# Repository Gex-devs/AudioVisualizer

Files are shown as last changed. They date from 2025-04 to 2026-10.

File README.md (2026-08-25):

# STM32 Audio visualizer DOT MATRIX

Video

Audio Visualizer based on STM32 bluepill utilizing Fast FFT and hacky trick to make the Matrix LED working nicely together. 

## Compact Size

Made a Add-on type PCB that laches on the back of the LED matrix.

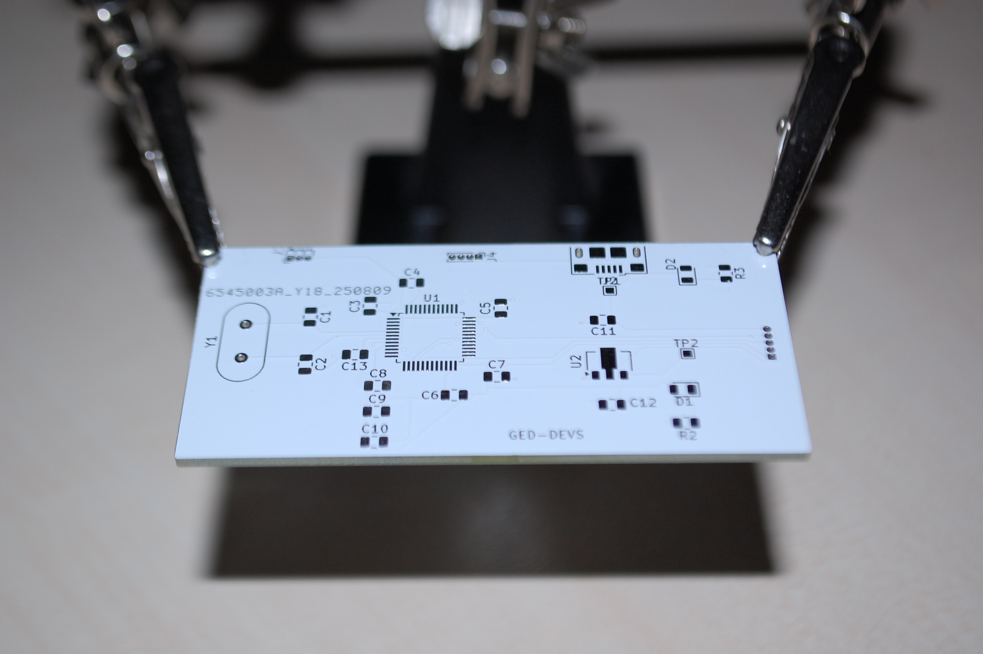
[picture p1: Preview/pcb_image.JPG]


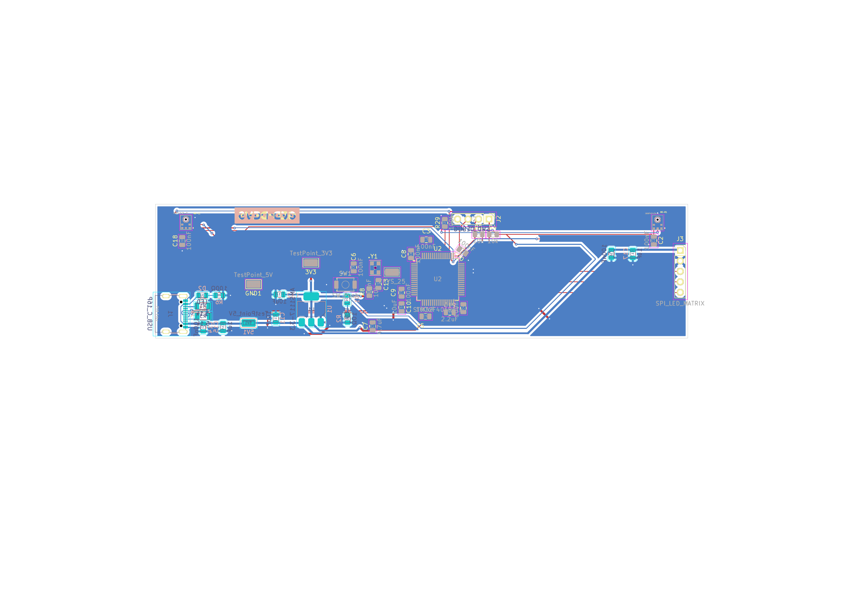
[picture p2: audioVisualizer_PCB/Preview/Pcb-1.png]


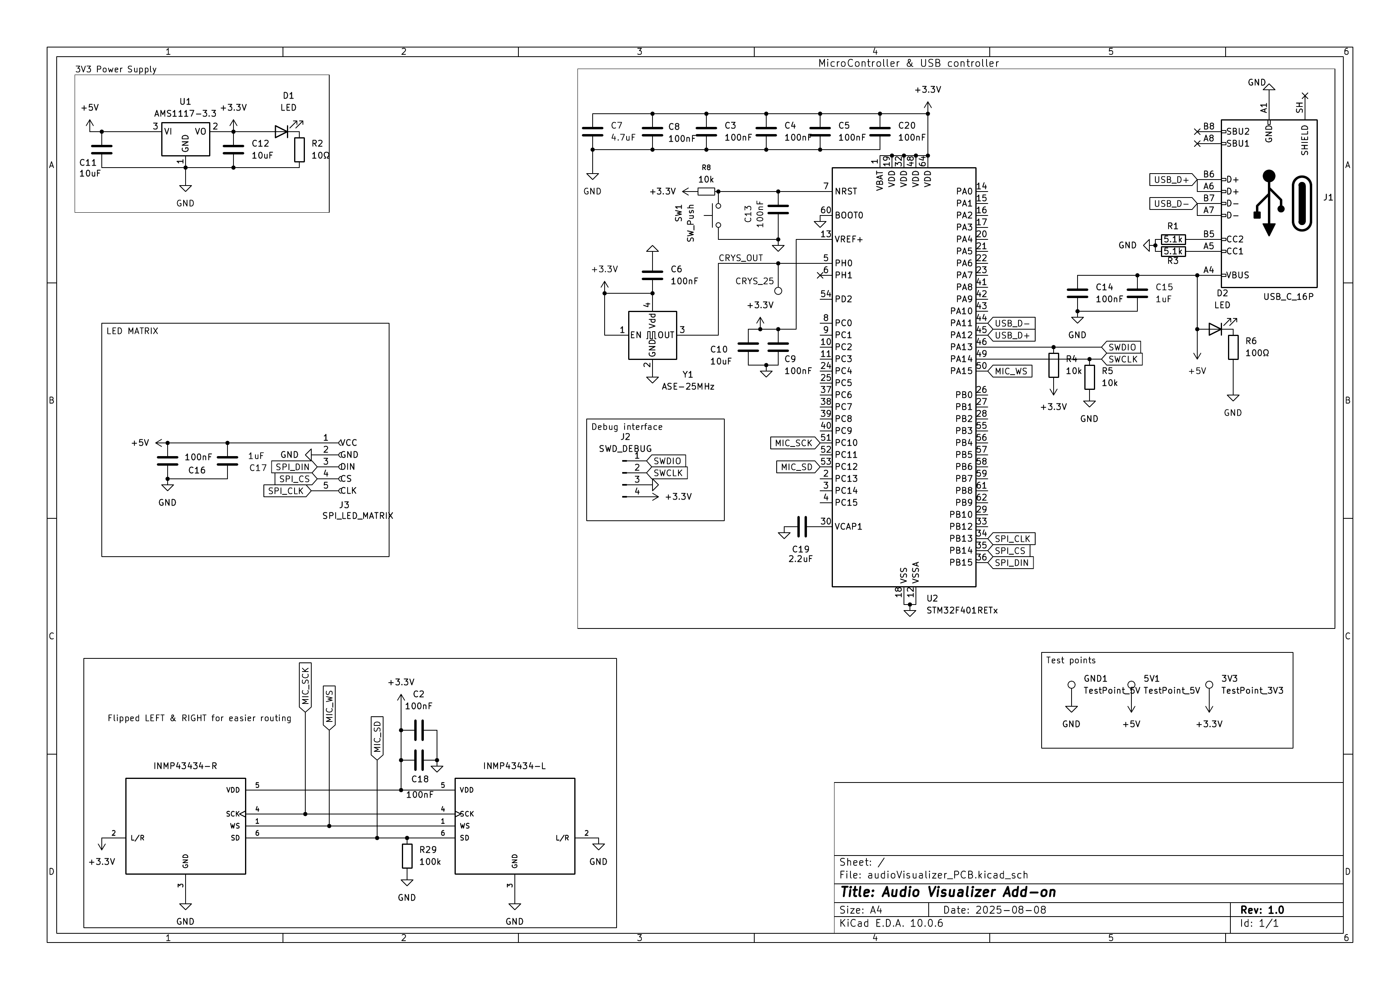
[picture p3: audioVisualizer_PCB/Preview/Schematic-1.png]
Document


## Components 
The Audio Visualizer features Real-time audio visualization with Fast Fourier Transform (FFT) to accurately visualize real audio frequencies rather than just detecting high or low noise levels.

* STM32 Bluepill
* MAX4466 Microphone Module
* 8x8 Matrix LED * 4

## Software Used

* [Kicad](https://www.kicad.org/) : PCB Design 
* [STM32MAX](https://www.st.com/en/development-tools/stm32cubemx.html) : Project Configurator 
* [T-filter](http://t-filter.engineerjs.com/) : Desgning Fir filter

## Tools Used

* Lab power supply
* Oscilloscope 
* ST-LINK/V2 debugger

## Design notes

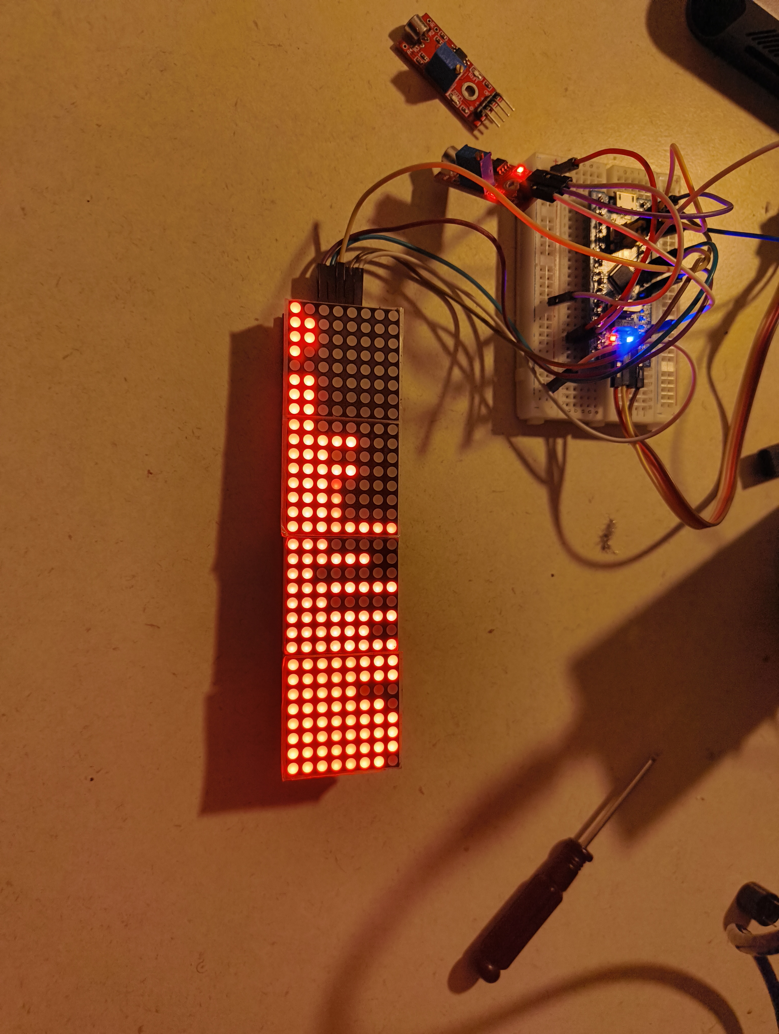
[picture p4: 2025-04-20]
Preview/Image.jpg

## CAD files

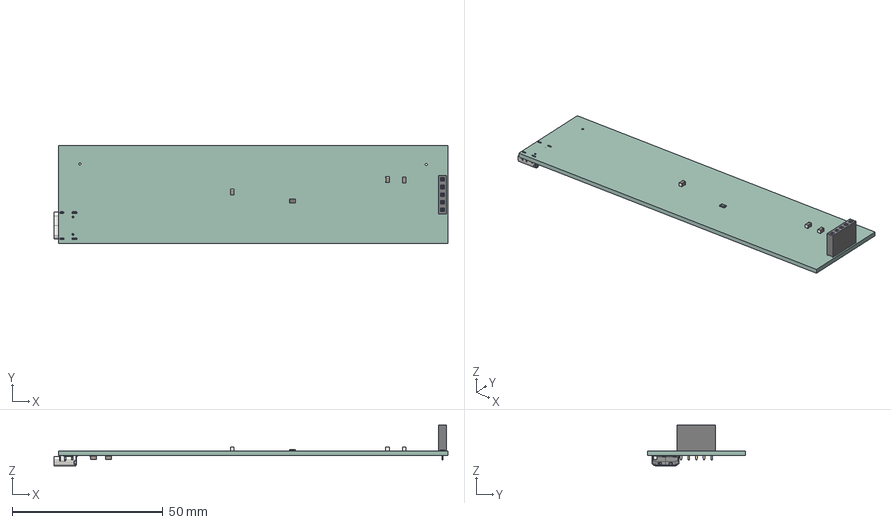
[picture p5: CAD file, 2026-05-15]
audioVisualizer_PCB/.step
130.6 x 32.5 x 13.5 mm
C_0805_2012Metric x 5
PinSocket_1x05_P2.54mm_Vertical
R_0805_2012Metric x 3
USB_C_Receptacle_GCT_USB4105-xx-A_16P_TopMnt_Horizontal
audioVisualizer_PCB_PCB

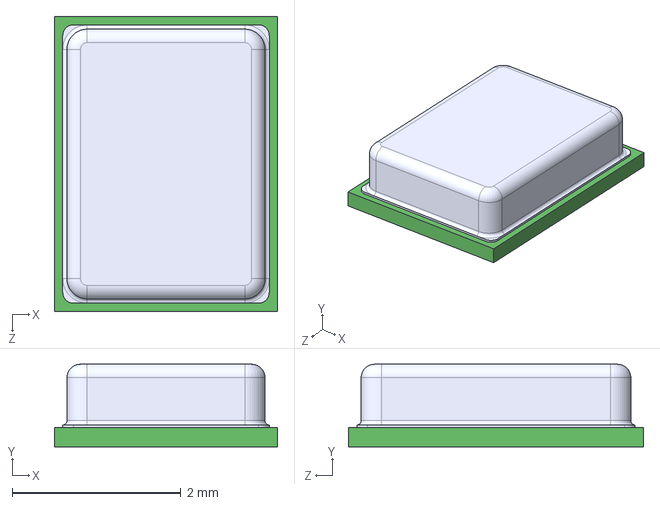
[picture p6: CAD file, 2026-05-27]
audioVisualizer_PCB/3dparts/ICS-43434.step
2.65 x 0.98 x 3.50 mm

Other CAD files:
audioVisualizer_PCB/Production/audioVisualizer_PCB-B_Paste.dxf

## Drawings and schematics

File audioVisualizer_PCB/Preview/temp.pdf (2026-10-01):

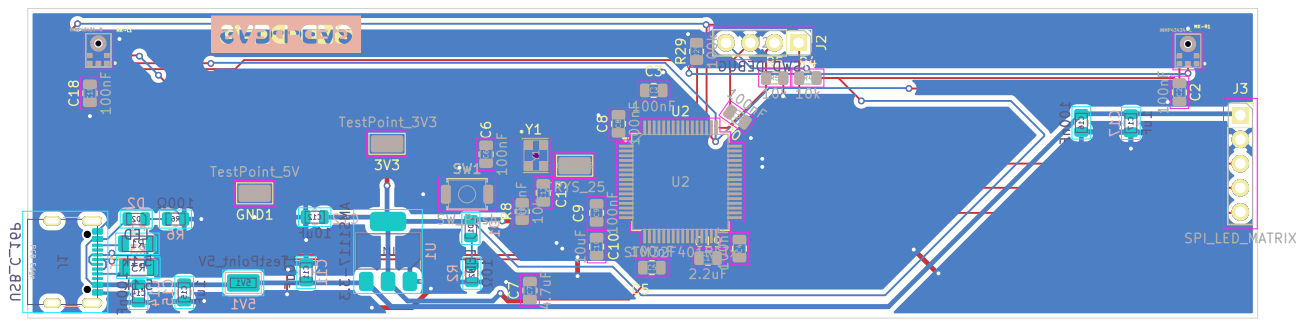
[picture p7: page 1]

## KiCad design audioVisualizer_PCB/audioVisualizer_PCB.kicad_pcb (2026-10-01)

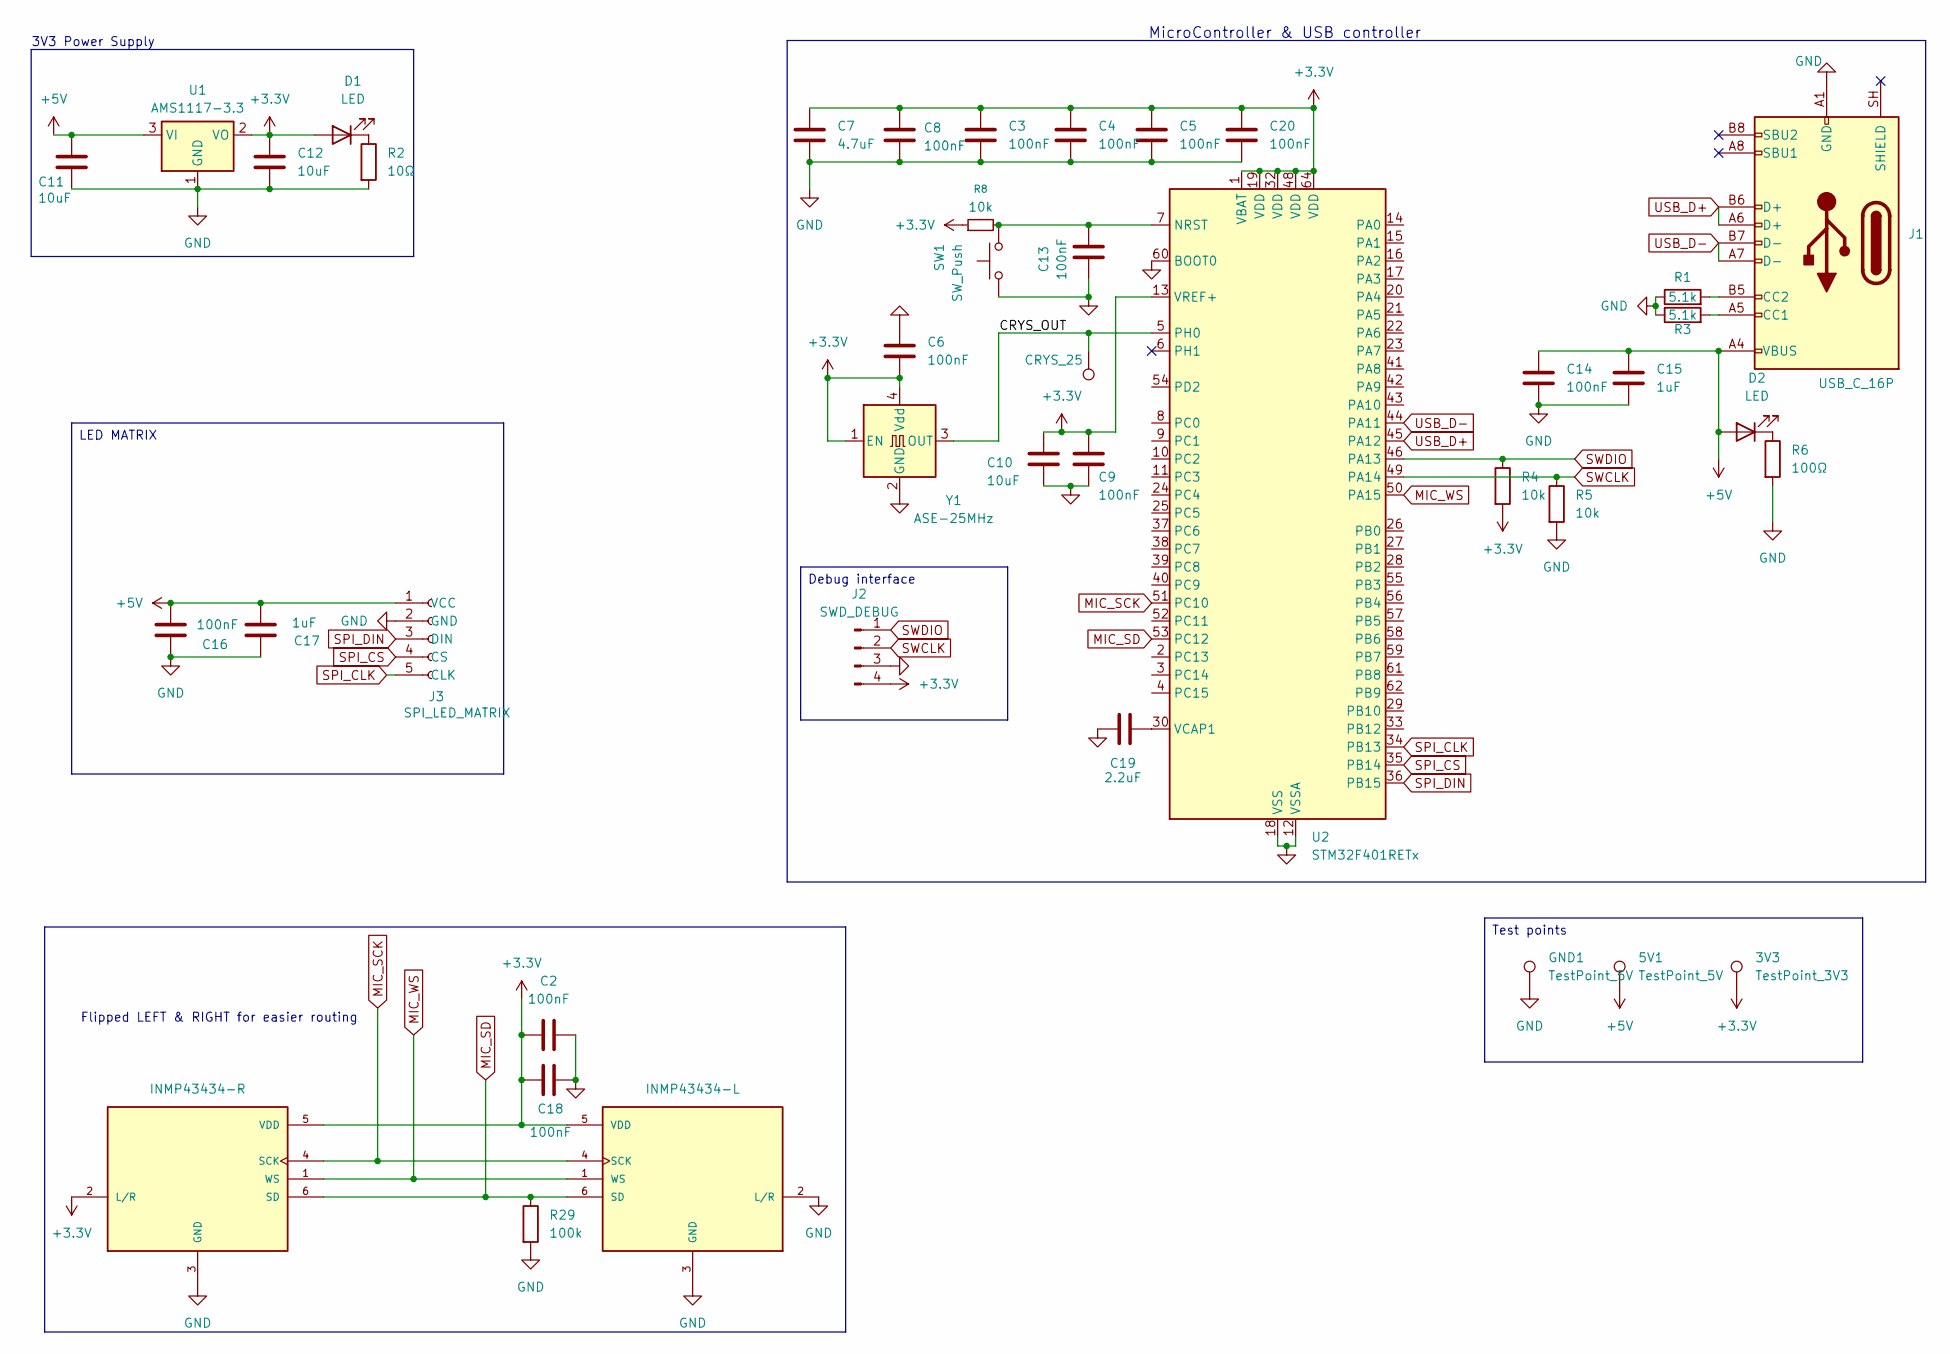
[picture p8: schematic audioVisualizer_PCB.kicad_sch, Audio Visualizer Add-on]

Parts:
3V3: TestPoint_3V3; TestPoint_Keystone_5015_Micro_Mini
5V1: TestPoint_5V; TestPoint_Keystone_5015_Micro_Mini
C2, C3, C4, C5, C6, C8, C9, C13, C14, C16, C18, C20: 100nF; C_0805_2012Metric
C7: 4.7uF; C_0805_2012Metric
C10, C11, C12: 10uF; C_0805_2012Metric
C15, C17: 1uF; C_0805_2012Metric
C19: 2.2uF; C_0805_2012Metric
CRYS_25: CRYS_25; TestPoint_Keystone_5015_Micro_Mini
D1, D2: LED; LED_0805_2012Metric
GND1: TestPoint_5V; TestPoint_Keystone_5015_Micro_Mini
J1: USB_C_16P; USB_C_Receptacle_GCT_USB4105-xx-A_16P_TopMnt_Horizontal
J2: SWD_DEBUG; PinHeader_1x04_P2.54mm_Vertical
J3: SPI_LED_MATRIX; PinSocket_1x05_P2.54mm_Vertical
MK-L1: INMP43434-R; MIC_ICS-43434; PARTREV 1.1
MK-R1: INMP43434-L; MIC_ICS-43434; PARTREV 1.1
R1, R3: 5.1k; R_1206_3216Metric
R2: 10Ω; R_0805_2012Metric
R4, R5, R8: 10k; R_0805_2012Metric
R6: 100Ω; R_0805_2012Metric
R29: 100k; R_0805_2012Metric
SW1: SW_Push; SW_SPST_TS-1088-xR020
U1: AMS1117-3.3; SOT-223-3_TabPin2
U2: STM32F401RETx; LQFP-64_10x10mm_P0.5mm
Y1: ASE-25MHz; Oscillator_SMD_EuroQuartz_XO32-4Pin_3.2x2.5mm

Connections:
+3.3V: 3V3.1 (1_1), C2.1, C3.1, C4.1, C5.1, C6.2, C7.1, C8.1, C9.1, C10.1, C12.1, C18.2, C20.1, D1.2 (A), J2.4, MK-L1.2 (L/R), MK-L1.5 (VDD), MK-R1.5 (VDD), R4.2, R8.1, U1.2 (VO), U2.1 (VBAT), U2.13 (VREF+), U2.19 (VDD), U2.32 (VDD), U2.48 (VDD), U2.64 (VDD), Y1.1 (EN), Y1.4 (Vdd)
+5V: 5V1.1 (1_1), C11.1, C14.2, C15.1, C16.2, C17.1, D2.2 (A), J1.A4 (VBUS), J1.A9 (VBUS), J1.B4 (VBUS), J1.B9 (VBUS), J3.1 (VCC), U1.3 (VI)
/CRYS_OUT: CRYS_25.1 (1_1), U2.5 (PH0), Y1.3 (OUT)
GND: C2.2, C3.2, C4.2, C5.2, C6.1, C7.2, C8.2, C9.2, C10.2, C11.2, C12.2, C13.2, C14.1, C15.2, C16.1, C17.2, C18.1, C19.2, C20.2, GND1.1 (1_1), J1.A1 (GND), J1.A12 (GND), J1.B1 (GND), J1.B12 (GND), J2.3, J3.2 (GND), MK-L1.3 (GND), MK-R1.2 (L/R), MK-R1.3 (GND), R1.1, R2.2, R3.1, R5.2, R6.2, R29.2, SW1.1, U1.1 (GND), U2.12 (VSSA), U2.18 (VSS), U2.31 (VSS), U2.47 (VSS), U2.60 (BOOT0), U2.63 (VSS), Y1.2 (GND)
MIC_SCK: MK-L1.4 (SCK), MK-R1.4 (SCK), U2.51 (PC10)
MIC_SD: MK-L1.6 (SD), MK-R1.6 (SD), R29.1, U2.53 (PC12)
MIC_WS: MK-L1.1 (WS), MK-R1.1 (WS), U2.50 (PA15)
unnamed: D1.1 (K), R2.1
unnamed: D2.1 (K), R6.1
unnamed: J1.A5 (CC1), R3.2
unnamed: J1.B5 (CC2), R1.2
unnamed: C13.1, R8.2, SW1.2, U2.7 (NRST)
unnamed: C19.1, U2.30 (VCAP1)
SPI_CLK: J3.5 (CLK), U2.34 (PB13)
SPI_CS: J3.4 (CS), U2.35 (PB14)
SPI_DIN: J3.3 (DIN), U2.36 (PB15)
SWCLK: J2.2, R5.1, U2.49 (PA14)
SWDIO: J2.1, R4.1, U2.46 (PA13)
USB_D+: J1.A6 (D+), J1.B6 (D+), U2.45 (PA12)
USB_D-: J1.A7 (D-), J1.B7 (D-), U2.44 (PA11)

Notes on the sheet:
MicroController & USB controller
3V3 Power Supply
Flipped LEFT & RIGHT for easier routing
Test points
Debug interface
LED MATRIX

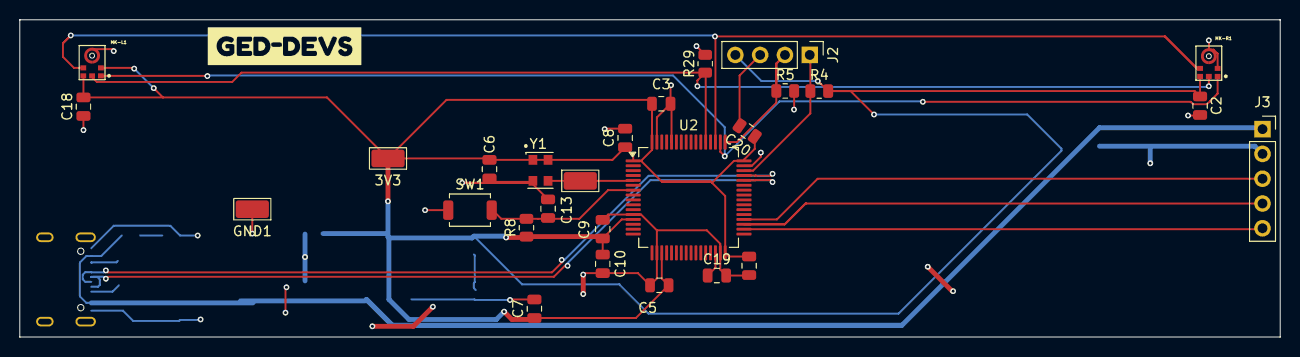
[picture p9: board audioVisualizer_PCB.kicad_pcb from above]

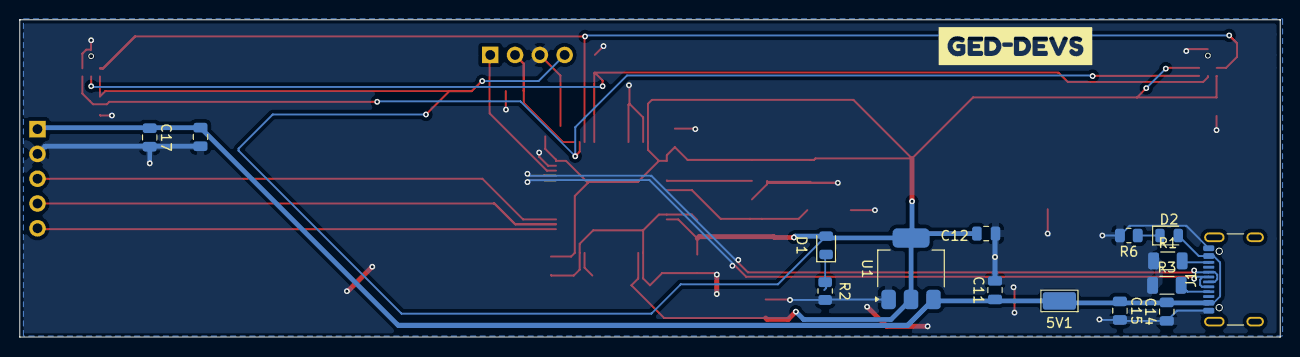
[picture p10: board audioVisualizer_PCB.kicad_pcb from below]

Board: 2 copper layers, 129.1 x 32.5 mm, 44 parts (16 on the bottom side), 20 nets.

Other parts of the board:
kibuzzard-69F6314F, kibuzzard-69F6314F#2: G***; kibuzzard-69F6314F

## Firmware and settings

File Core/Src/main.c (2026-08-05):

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
/* Includes ------------------------------------------------------------------*/
#include "main.h"

/* USER CODE BEGIN Includes */
#include <stdbool.h>
#include <stdlib.h>
#include <string.h>
#include <arm_math.h>
#include <arduino_utils.h>
/* USER CODE END Includes */

/* USER CODE BEGIN PTD */
typedef struct
{
  int bin_low;
  int bin_high;
} LogBinMap;
/* USER CODE END PTD */

/* USER CODE BEGIN PM */
#define MATRIX_DISPLAY_UNIT1 0
#define FFT_LENGTH 64
#define BUFFER_SIZE (FFT_LENGTH) // 24bits 32 data frame
#define MATRIX_X 32
#define MATRIX_Y 8

#define SAMPLE_RATE 16000.0f
#define MIN_FREQ 2000.0f
#define MAX_FREQ 7000.0f
/* USER CODE END PM */

I2S_HandleTypeDef hi2s3;

SPI_HandleTypeDef hspi2;

TIM_HandleTypeDef htim2;

UART_HandleTypeDef huart6;

HCD_HandleTypeDef hhcd_USB_OTG_FS;

/* USER CODE BEGIN PV */
bool i2s_dma_full_flag = false;
bool i2s_dma_half_flag = false;

arm_status status_fft;
arm_fir_instance_f32 fir;
arm_rfft_fast_instance_f32 fft_instance;

float32_t input_fft[FFT_LENGTH];
float32_t output_fft[FFT_LENGTH];
float32_t output_fft_mag[FFT_LENGTH / 2];
float32_t output_bins[MATRIX_X];
uint32_t i2s_buffer[BUFFER_SIZE];

LogBinMap lut[MATRIX_X];

float32_t window_coff[FFT_LENGTH];

float32_t data_avgs[MATRIX_X];

int yvalue;
int peaks[MATRIX_X] = {0};
int displaycolumn, displayvalue;

int MY_ARRAY[] = {0, 128, 192, 224, 240, 248, 252, 254, 255};

void build_log_bin_lut(LogBinMap *lut, int NUM_BINS)
{
  int fft_bins = FFT_LENGTH / 2;
  float32_t freq_resolution = SAMPLE_RATE / (float32_t)FFT_LENGTH;

  float32_t log_min = log2f(MIN_FREQ);
  float32_t log_max = log2f(MAX_FREQ);
  float32_t log_range = log_max - log_min;

  for (int i = 0; i < NUM_BINS; i++)
  {
    float32_t freq_low = powf(2.0f, log_min + (float32_t)i / NUM_BINS * log_range);
    float32_t freq_high = powf(2.0f, log_min + (float32_t)(i + 1) / NUM_BINS * log_range);

    int bin_low = (int)floorf(freq_low / freq_resolution);
    int bin_high = (int)ceilf(freq_high / freq_resolution);

    bin_low = bin_low < 0 ? 0 : bin_low;
    bin_high = bin_high >= fft_bins ? fft_bins - 1 : bin_high;

    if (bin_low > bin_high)
      bin_high = bin_low;

    lut[i].bin_low = bin_low;
    lut[i].bin_high = bin_high;
  }
}

void rebin_log_audio(float *fft_mag, float *rebin, const LogBinMap *lut, int NUM_BINS)
{
  for (int i = 0; i < NUM_BINS; i++)
  {
    int bin_low = lut[i].bin_low;
    int bin_high = lut[i].bin_high;

    float32_t sum = 0.0f;
    int count = bin_high - bin_low + 1;

    for (int j = bin_low; j <= bin_high; j++)
      sum += fft_mag[j];

    rebin[i] = sum / (float32_t)count;
  }
}
/*

FIR filter designed with
http://t-filter.appspot.com

sampling frequency: 16000 Hz

* 0 Hz - 3000 Hz
  gain = 0
  desired attenuation = -40 dB
  actual attenuation = -41.44566068037808 dB

* 4000 Hz - 8000 Hz
  gain = 1
  desired ripple = 5 dB
  actual ripple = 3.5163656958569183 dB

*/

#define FILTER_TAP_NUM 19

static float32_t filter_taps[FILTER_TAP_NUM] = {
    -0.01286737409931033,
    -0.011582917042481518,
    0.0709435597229363,
    -0.05850997474212666,
    -0.040910558942368495,
    0.03894710089289564,
    0.0947634922313574,
    -0.04258608472470373,
    -0.31412123784627477,
    0.543381234624982,
    -0.31412123784627477,
    -0.04258608472470373,
    0.0947634922313574,
    0.03894710089289564,
    -0.040910558942368495,
    -0.05850997474212666,
    0.0709435597229363,
    -0.011582917042481518,
    -0.01286737409931033};

float32_t firState[FILTER_TAP_NUM + FFT_LENGTH - 1];

/* USER CODE END PV */

void SystemClock_Config(void);
static void MX_GPIO_Init(void);
static void MX_I2S3_Init(void);
static void MX_SPI2_Init(void);
static void MX_USB_OTG_FS_HCD_Init(void);
static void MX_TIM2_Init(void);
static void MX_USART6_UART_Init(void);
/* USER CODE BEGIN PFP */
void audio_visualizer_update(float32_t *fft_magnitudes);
void process_audio_data(float32_t *output_fft_mag);
void test_visualizer_sine(void);
/* USER CODE END PFP */

/* USER CODE BEGIN 0 */
void test_visualizer_sine(void)
{
  static float32_t sweep_freq = 200.0f;
  static float32_t sweep_dir = 1.0f;

  float32_t phase_inc = 2.0f * M_PI * sweep_freq / 16000.0f; // 16kHz here
  float32_t ph = 0.0f;

  for (int i = 0; i < FFT_LENGTH; i++)
  {
    input_fft[i] = 500000.0f * sinf(ph);
    ph += phase_inc;
    if (ph >= 2.0f * M_PI)
      ph -= 2.0f * M_PI;
  }

  float32_t mean = 0.0f;
  for (int i = 0; i < FFT_LENGTH; i++)
    mean += input_fft[i];
  mean /= FFT_LENGTH;
  for (int i = 0; i < FFT_LENGTH; i++)
    input_fft[i] -= mean;
  for (int i = 0; i < FFT_LENGTH; i++)
    input_fft[i] *= window_coff[i];

  arm_rfft_fast_f32(&fft_instance, input_fft, output_fft, 0);
  arm_cmplx_mag_f32(output_fft, output_fft_mag, FFT_LENGTH / 2);
  audio_visualizer_update(output_fft_mag);

  // Sweep 200Hz → 7500Hz (stay safely below 8000Hz Nyquist limit)
  sweep_freq += sweep_dir * 200.0f;
  if (sweep_freq >= 7500.0f)
    sweep_dir = -1.0f;
  if (sweep_freq <= 200.0f)
    sweep_dir = 1.0f;

  HAL_Delay(80);
}

/**
 * @brief input i2s buffer, reconstuct and return magnitude, implemented for inmp411
 * @return float32_t
 */
void process_audio_data(float32_t *output_fft_mag)
{
  for (int i = 0; i < FFT_LENGTH - 1; i++)
  {
    int32_t left = i2s_buffer[i];
    int32_t right = i2s_buffer[i + 1];

    // squre the audio channels
    right = right * right; // R^2
    left = left * left;    // L^2

    // root mean square https://en.wikipedia.org/wiki/Root_mean_square
    double sample = sqrt((left + right) / 2);
    // int32_t sample = (left + right) / 2; // average

    input_fft[i] = (float32_t)sample; // Store in FFT input buffer as float
  }

  // Applying High-pass filter
  // arm_fir_f32(&fir, input_fft, input_fft, FFT_LENGTH);

  float mean = 0;
  for (int i = 0; i < FFT_LENGTH; i++)
  {
    mean += input_fft[i]; // Calculate mean for DC offset removal
  }
  mean /= FFT_LENGTH;

  for (int i = 0; i < FFT_LENGTH; i++)
  {
    input_fft[i] -= mean; // DC offset removal
  }

  for (int i = 0; i < FFT_LENGTH; i++)
  {
    input_fft[i] *= window_coff[i]; // Apply Window
  }

  arm_rfft_fast_f32(&fft_instance, input_fft, output_fft, 0); // Fast FFT
  // arm_fir_f32(&fir, output_fft, output_fft, FFT_LENGTH);         // apply filter
  arm_cmplx_mag_f32(output_fft, output_fft_mag, FFT_LENGTH / 2); // Get mag values
}

// TODO: Optimize this, it's hard to read.
void audio_visualizer_update(float32_t *output_fft_mag)
{
  // Find max magnitude this frame for self-normalization
  float32_t max_mag = 0.0f;
  arm_max_f32(output_fft_mag, FFT_LENGTH / 2, &max_mag, NULL);

  // Noise floor gate — skip update if signal is too quiet
  if (max_mag < 5000.0f)
  {
    for (int i = 0; i < MATRIX_X; i++)
    {
      peaks[i] -= 1;
      if (peaks[i] < 0)
        peaks[i] = 0;
      SET_COLUMN(MATRIX_DISPLAY_UNIT1, 31 - i, reverse_bits(MY_ARRAY[peaks[i]]));
    }
    return;
  }

  for (int i = 0; i < MATRIX_X; i++)
  {
    // Normalize 0.0–1.0 then scale to MATRIX_Y
    float32_t normalized = output_fft_mag[i] / max_mag;
    int yvalue = (int)(normalized * MATRIX_Y);
    if (yvalue > MATRIX_Y)
      yvalue = MATRIX_Y; // clamp

    // Peak decay — clamped to 0
    peaks[i] -= 1;
    if (peaks[i] < 0)
      peaks[i] = 0;
    if (yvalue > peaks[i])
      peaks[i] = yvalue;

    displayvalue = MY_ARRAY[peaks[i]];
    displaycolumn = 31 - i;
    SET_COLUMN(MATRIX_DISPLAY_UNIT1, displaycolumn, reverse_bits(displayvalue));
  }
}
/* USER CODE END 0 */

/**
  * @brief  The application entry point.
  * @retval int
  */
int main(void)
{

  /* MCU Configuration--------------------------------------------------------*/

  /* Reset of all peripherals, Initializes the Flash interface and the Systick. */
  HAL_Init();

  /* Configure the system clock */
  SystemClock_Config();

  /* Initialize all configured peripherals */
  MX_GPIO_Init();
  MX_I2S3_Init();
  MX_SPI2_Init();
  MX_USB_OTG_FS_HCD_Init();
  MX_TIM2_Init();
  MX_USART6_UART_Init();
  /* USER CODE BEGIN 2 */
  DOT_MATRIX_Init_TMR(&hspi2, &htim2);
  MATRIX_CLEAR(MATRIX_DISPLAY_UNIT1);

  // Create fast fft instance
  status_fft = arm_rfft_fast_init_f32(&fft_instance, FFT_LENGTH);

  arm_fir_init_f32(&fir, FILTER_TAP_NUM, filter_taps, firState, FFT_LENGTH);

  arm_hamming_f32(window_coff, FFT_LENGTH); // Generate Window coefficients

  // build lut for log rebinning
  build_log_bin_lut(lut, MATRIX_X);

  HAL_I2S_Receive_DMA(&hi2s3, (uint16_t *)i2s_buffer, BUFFER_SIZE);
  /* USER CODE END 2 */

  /* Infinite loop */
  /* USER CODE BEGIN WHILE */
  while (1)
  {
    /* USER CODE END WHILE */

    /* USER CODE BEGIN 3 */
    // Sampling at
    // if (i2s_dma_half_flag)
    // {
    //   float32_t out_mag[FFT_LENGTH / 2];
    //   float32_t output_bins[FFT_LENGTH / 2];

    //   process_audio_data(&i2s_buffer[0], &out_mag[0]); // Process second half of the buffer
    //   rebin_log_audio(out_mag, output_bins, lut, MATRIX_X); // Optional: re-bin FFT magnitudes into logarithmic frequency bins matching the display columns
    //   audio_visualizer_update(output_bins);
    //   i2s_dma_half_flag = false;
    //   // Sample microphone input
    // }

    if (i2s_dma_full_flag)
    {
      float32_t out_mag[FFT_LENGTH / 2];
      // float32_t output_bins[FFT_LENGTH / 2];

      process_audio_data(out_mag);                      // Process second half of the buffer
      rebin_log_audio(out_mag, out_mag, lut, MATRIX_X); // Optional: re-bin FFT magnitudes into logarithmic frequency bins matching the display columns
      audio_visualizer_update(out_mag);                 // Update display based on FFT results
      i2s_dma_full_flag = false;
      // Sample microphone input
    }
    // test_visualizer_sine(); // Call this instead of process_audio_data() to test with a synthetic sine wave signal. Comment out the above if blocks when using this.
  }
  /* USER CODE END 3 */
}

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
/* USER CODE BEGIN 4 */
// Half buffer ready (0..63)
void HAL_I2S_RxHalfCpltCallback(I2S_HandleTypeDef *hi2s)
{
  i2s_dma_half_flag = true;
}

// Full buffer ready (64..127)
void HAL_I2S_RxCpltCallback(I2S_HandleTypeDef *hi2s)
{
  i2s_dma_full_flag = true;
}
void HAL_TIM_PeriodElapsedCallback(TIM_HandleTypeDef *htim)
{
  MATRIX_TMR_OVF_ISR(htim);
}
/* USER CODE END 4 */
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


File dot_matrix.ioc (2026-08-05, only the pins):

Mcu.UserName=STM32F401RETx
PA11.Signal=USB_OTG_FS_DM
PA12.Signal=USB_OTG_FS_DP
PA13.Signal=SYS_JTMS-SWDIO
PA14.Signal=SYS_JTCK-SWCLK
PA15.Signal=I2S3_WS
PA9.Signal=USB_OTG_FS_VBUS
PB13.Signal=SPI2_SCK
PB14.Signal=GPIO_Output
PB15.Signal=SPI2_MOSI
PC10.Signal=I2S3_CK
PC12.Signal=I2S3_SD
PC6.Signal=USART6_TX
PC7.Signal=USART6_RX

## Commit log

2025-04-20 Working module with LED matrix library modification
2025-08-01 applied hann window and added high-pass filter, good visuals
2025-08-01 fixed visual mapping, Issue still in Bar index 0 - 10
    [main.c]
2025-08-08 added filter, updated ReadME, added PCB
    [audioVisualizer_PCB-B_Cu.gbl, audioVisualizer_PCB-B_Mask.gbs, audioVisualizer_PCB-B_Paste.gbp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]
2025-08-08 Moved the interactive BOM to root for deployment
2025-08-19 added fritzing project for prototype
    [AudioVisualizer.fzz]
2025-08-19 added image of the Printed pcb
2025-08-28 unfinished workflow and update on the TH of the PCB footprint
    [audioVisualizer_PCB.kicad_pcb, audioVisualizer_PCB.kicad_sch]
2025-08-28 Fixed headerpin diameter, updated workflow
    [audioVisualizer_PCB.kicad_pcb, audioVisualizer_PCB.kicad_sch]
2025-08-28 workflow fix
    [audioVisualizer_PCB.kicad_sch]
2025-08-28 Update schematic preview [skip ci]
2025-08-28 testing workflow
    [audioVisualizer_PCB.kicad_sch]
2025-10-08 Added additional omni-directional smd mic, not routed or programmed
    [audioVisualizer_PCB-B_Cu.gbl, audioVisualizer_PCB-B_Mask.gbs, audioVisualizer_PCB-B_Paste.gbp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]
2026-02-14 break em out
    [MAX_Controller.kicad_sch, audioVisualizer_PCB.kicad_pcb, audioVisualizer_PCB.kicad_sch]
2026-04-14 migration to stm32f401
    [MAX_Controller.kicad_sch, audioVisualizer_PCB.kicad_pcb]
2026-04-20 changed mcu; implemented i2s succesfully; working fft; working visualizer; fixed clock issue; visualizer needs enhancement
    [dot_matrix.ioc, main.c]
2026-04-25 embeddeding the mcu is harder than I thought
    [MAX_Controller.kicad_sch, audioVisualizer_PCB.kicad_pcb, audioVisualizer_PCB.kicad_sch]
2026-04-30 added stereo mics; setup usb-c;fixed timer issue for led matrix; using external clock
    [AudioVisualizer.fzz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]
2026-05-02 finished pcb ready for production
    [audioVisualizer_PCB.kicad_pcb, audioVisualizer_PCB.kicad_sch]
2026-05-02 updated interactive bom
2026-05-06 updated kicad release to the latest version
2026-05-15 reflect on code as well
    [.step, audioVisualizer_PCB.kicad_pcb, audioVisualizer_PCB.kicad_sch]
2026-05-18 removed unused schematic
    [MAX_Controller.kicad_sch]
2026-06-09 manually routed the tracks; switch LEFT/RIGHT mic
    [audioVisualizer_PCB.kicad_pcb, audioVisualizer_PCB.kicad_sch]
2026-06-24 added cap for vref pin
    [audioVisualizer_PCB-B_Cu.gbl, audioVisualizer_PCB-B_Mask.gbs, audioVisualizer_PCB-B_Paste.gbp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]
2026-07-11 interactive bom updated
2026-07-23 update afer review; power fixed?
    [audioVisualizer_PCB.kicad_pcb, audioVisualizer_PCB.kicad_sch, untitled.kicad_sch]
2026-08-03 change data frame from 16bit to 24bit on 32bit data frame; not tested and verified
2026-08-04 new mcu
    [audioVisualizer_PCB.kicad_pcb, audioVisualizer_PCB.kicad_sch]
2026-08-05 clean up and hardcoding for 32x8 matrix led display
2026-08-05 updated actions and readme to upload pcb preview
    [audioVisualizer_PCB.kicad_pcb]
2026-08-05 Updated STM32 project
2026-08-25 updated workflow and removed production folder
    [audioVisualizer_PCB-B_Cu.gbl, audioVisualizer_PCB-B_Mask.gbs, audioVisualizer_PCB-B_Paste.gbp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]
2026-09-27 add decoup for VREF+ pin
    [audioVisualizer_PCB-B_Paste.dxf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]
2026-10-01 connected the usb, incase it worked
    [audioVisualizer_PCB.kicad_pcb, audioVisualizer_PCB.kicad_sch]
2026-10-17 PCB & Firmware Ok. Fixed some reconstruction

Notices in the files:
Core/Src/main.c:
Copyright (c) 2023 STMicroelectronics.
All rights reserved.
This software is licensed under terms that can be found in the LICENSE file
